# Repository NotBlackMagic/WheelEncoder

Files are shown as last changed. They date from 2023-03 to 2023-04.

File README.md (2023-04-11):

# WheelEncoder
This repository contains the acquisition board hardware and firmware for a Wheel Encoder system developed for the NXP Mobile Robotics Buggy3 Kit, the [MR-Buggy3](https://www.nxp.com/design/designs/mobile-robotics-buggy3-kit-including-rddrone-fmuk66-and-peripherals:MR-BUGGY3). It was initially designed and developed during the NXP [HoverGames3](https://www.hackster.io/contests/nxp-hovergames-challenge-3), as part of my project for this competition: the [AutoSQA](https://www.hackster.io/NotBlackMagic/autonomous-soil-quality-assessment-autosqa-2eb2de). The Wheel Encoder system is composed of an acquisition board, with 4 inputs for HAL sensors (S49e) and multiple interfaces (I2C/UART/CAN), the hardware necessary to mount the HAL sensors to the MR-Buggy3 and the driver for the [PX4 Autopilot](https://px4.io/) to integrate it into this autopilot system, in this case running on the NXP [FMUK66](https://www.nxp.com/design/designs/px4-robotic-drone-vehicle-flight-management-unit-vmu-fmu-rddrone-fmuk66:RDDRONE-FMUK66).

<p align="center">
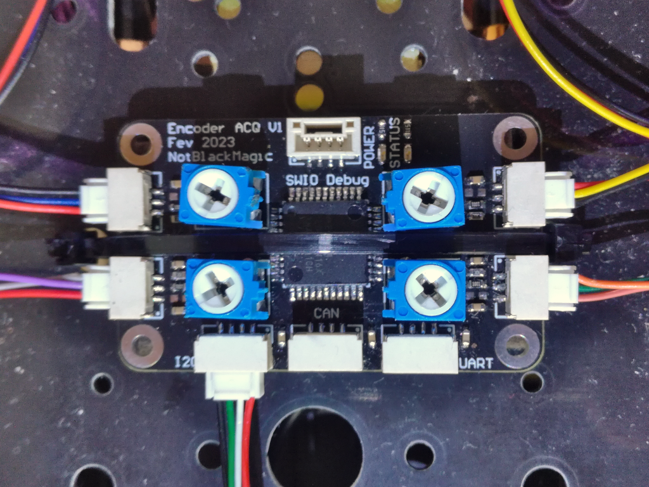
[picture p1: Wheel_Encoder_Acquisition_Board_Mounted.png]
Wheel Encoder Acquisition Board Mounted
	
</p>

More in-depth information and documentation on this Wheel Encoder system can be found on my website: https://notblackmagic.com/projects/wheel-encoder/

Also, a demo video showing how the system works and how it is integrated into the MR-Buggy3 and the PX4 autopilot, can be found on YouTube: https://youtu.be/qfiv8_sycEg

## Folder Structure
This folder contains the firmware code for the Wheel Encoder Acquisition board, developed with the NXP [MCUXpresso IDE](https://www.nxp.com/design/software/development-software/mcuxpresso-integrated-development-environment-ide:MCUXpresso-IDE). The relevant folders/files for this are **"/board, /device, /source, WheelEncoder.mex"**. The remaining folders contain necessary additional files:

**Arduino:** Contains the Arduino code for both the Arduino version of the wheel encoder and a test I2C encoder reader.

**Hardware:** Contains the files for the Wheel Encoder Acquisition board hardware (Gerber + Schematic) and the 3D files (.STL) for the HAL encoder holders for the MR-Buggy3 (WLToys 124019).

## PX4 Firmware
A custom fork of the PX4 firmware, forked from the V1.14 Beta version, contains the driver files for this Wheel Encoder, integrating it into the PX4 autopilot through standard **WheelEncoders.msg** uORB messages. The fork is available on my GitHub:

PX4 fork: https://github.com/NotBlackMagic/PX4-Autopilot/tree/Encoder

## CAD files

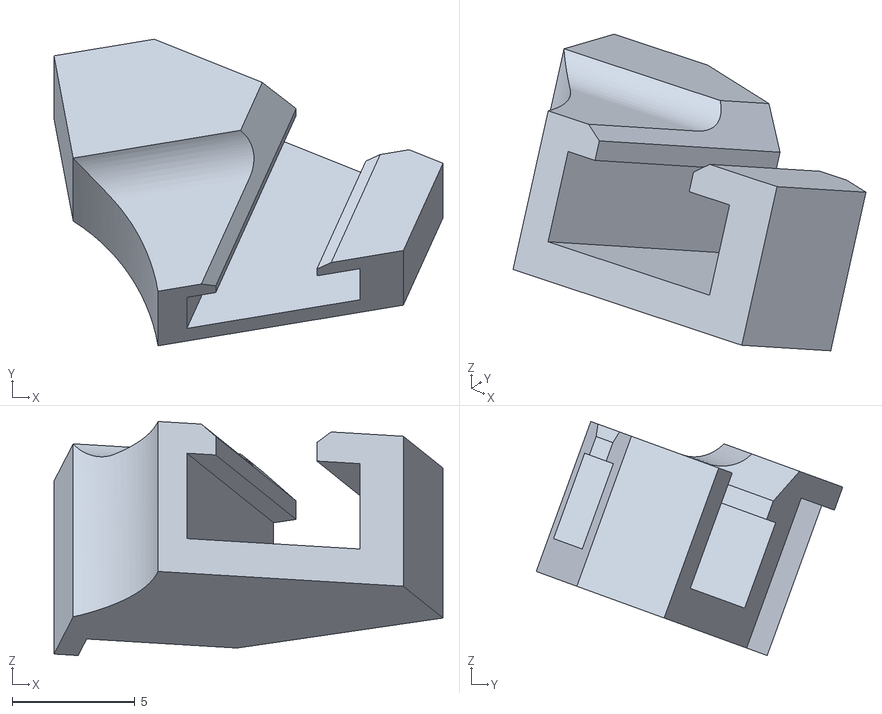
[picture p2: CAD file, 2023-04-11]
Hardware/HAL Holder V1.5 Front Left.stl
15.8 x 12.5 x 9.53

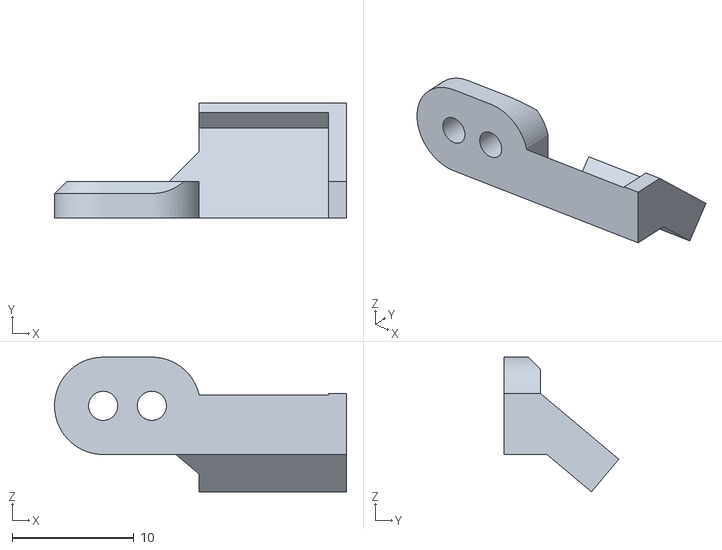
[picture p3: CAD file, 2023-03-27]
Hardware/HAL Holder V2 Back Left.stl
24.0 x 9.42 x 11.1

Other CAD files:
Hardware/HAL Holder V1.5 Front Right.stl.stl
Hardware/HAL Holder V2 Back Right.stl

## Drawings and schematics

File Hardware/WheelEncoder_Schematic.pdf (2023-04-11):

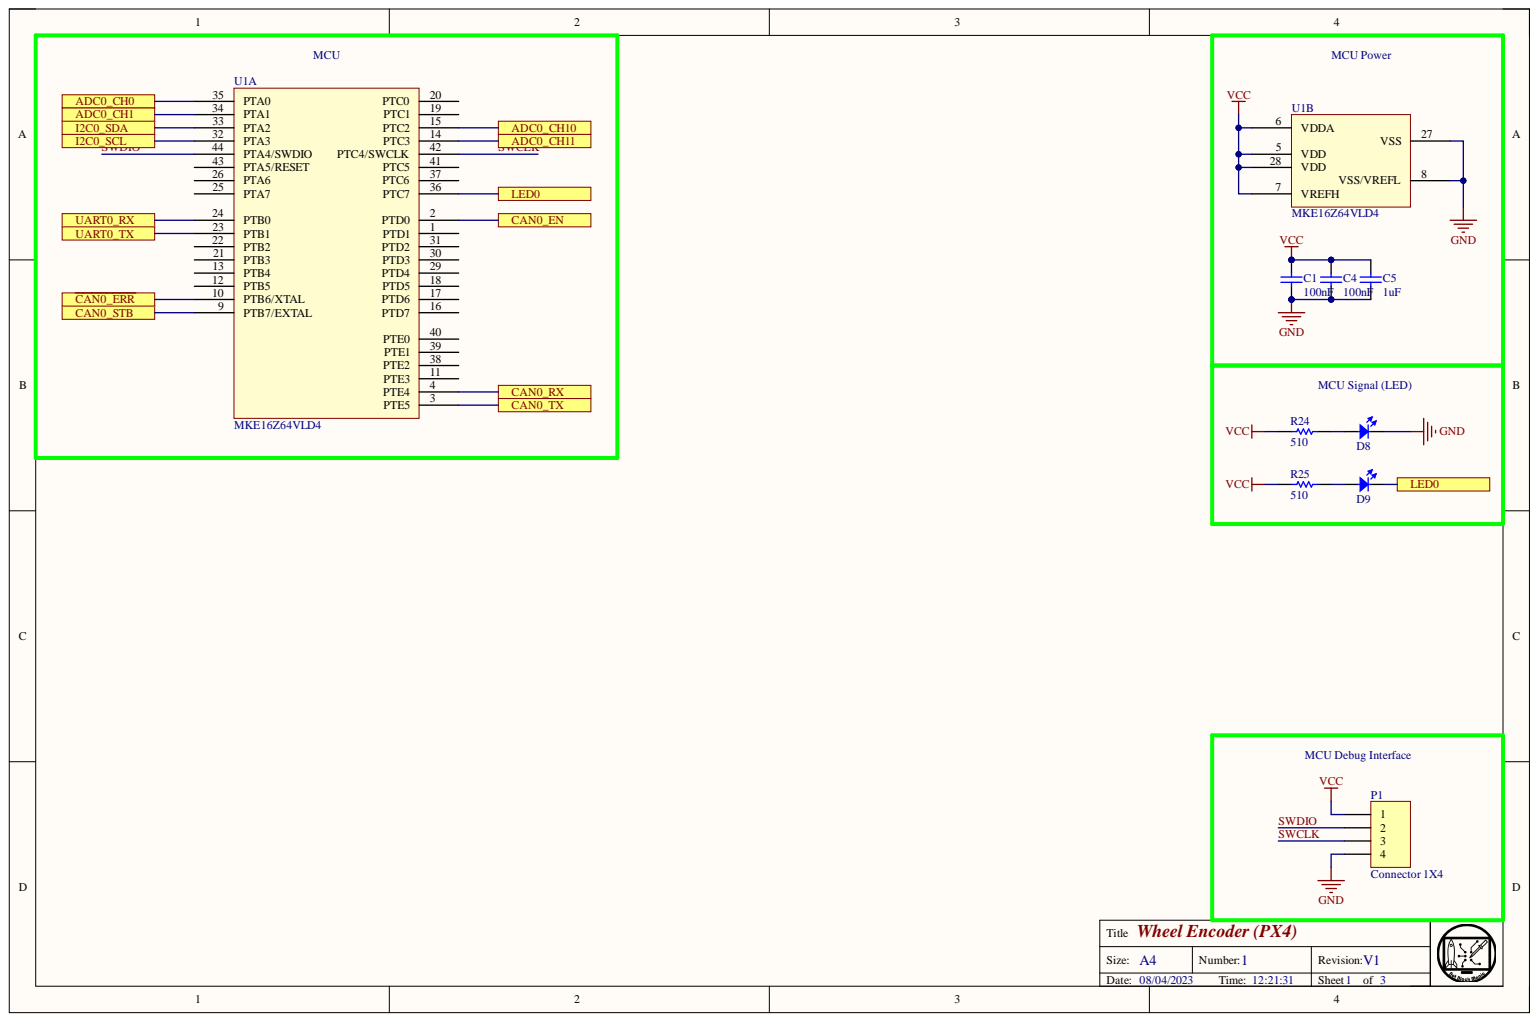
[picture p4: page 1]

VDD 5
VDD 28

Size: A4 | Number: 1 | Revision: V1
Date: 08/04/2023 Time: 12:21:31 | | Sheet 1 of 3

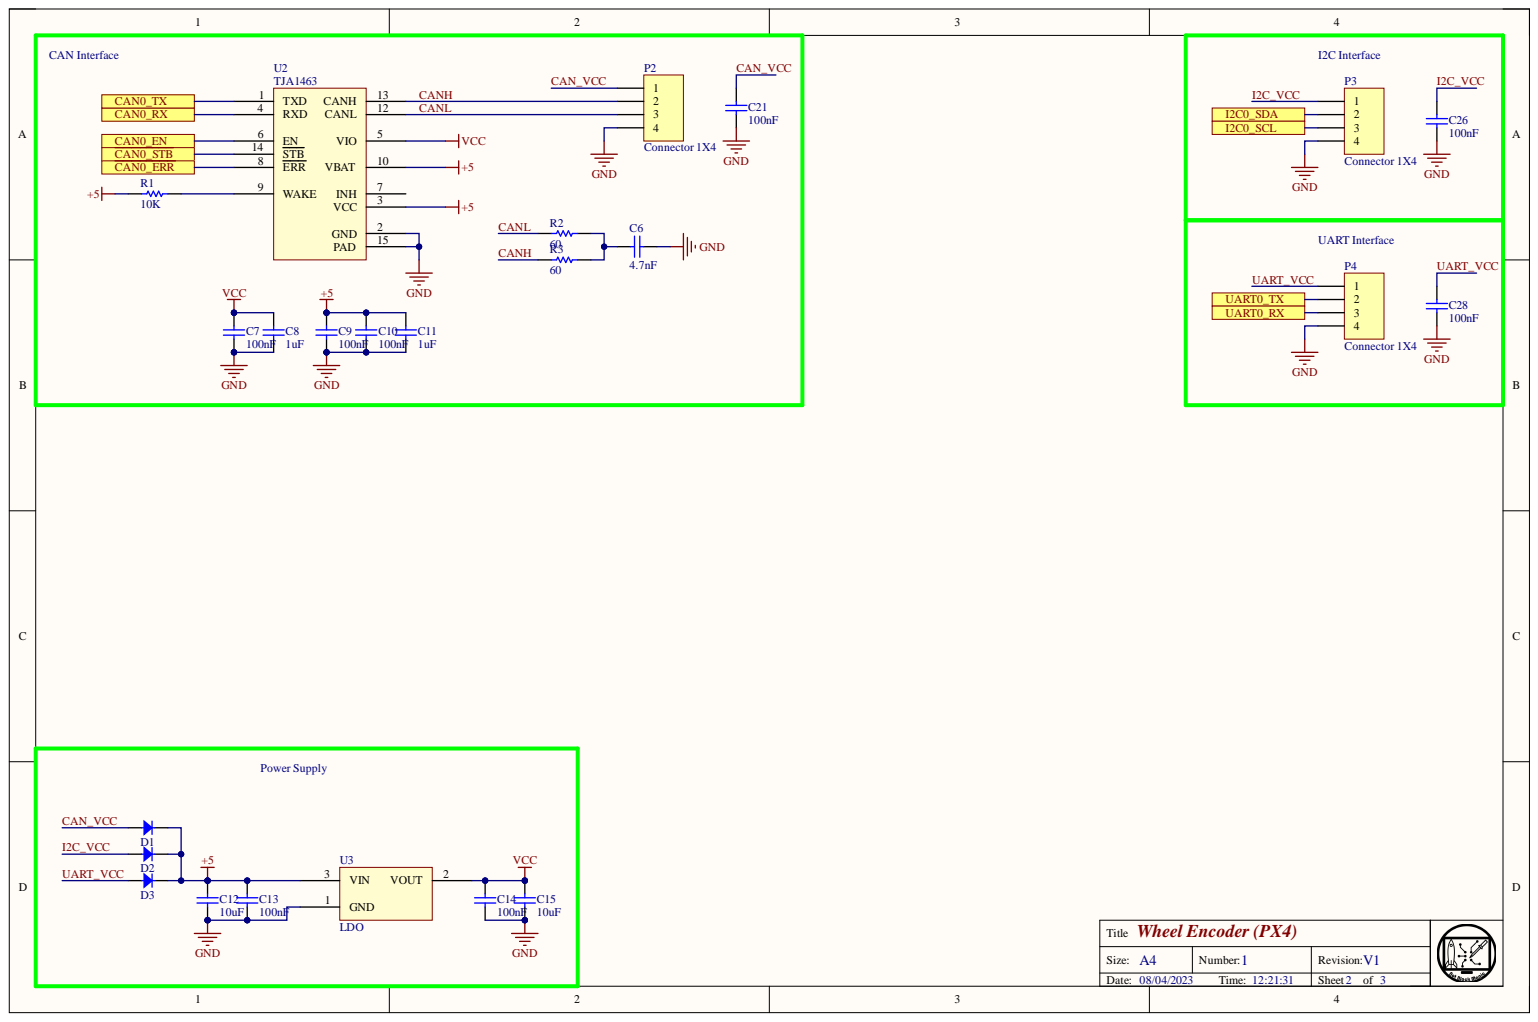
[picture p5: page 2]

Size: A4 | Number: 1 | Revision: V1
Date: 08/04/2023 Time: 12:21:31 | | Sheet 2 of 3

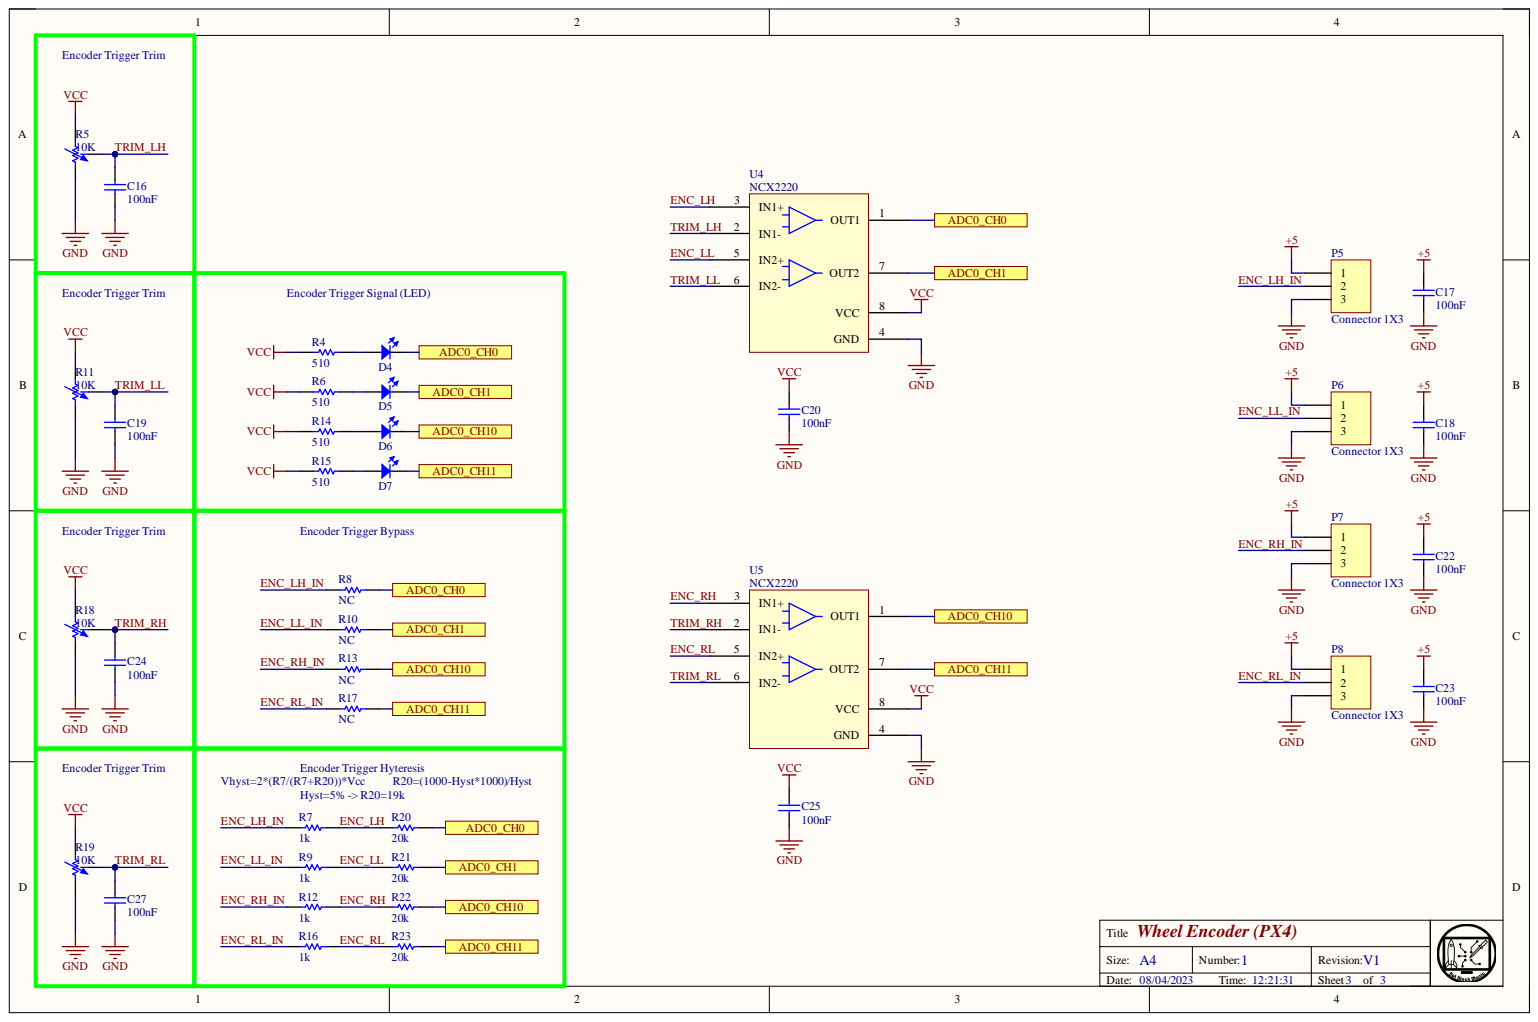
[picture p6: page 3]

VCC G N D

E nco der Tri g ger Tri m VCC 1 0 K TRIM_RL G N D D | der Tri g ger H y teres i s V h y s t=2 *(R7 /(R7+R2 0))* V c c R2 0=(1 0 0 0-H y s t * 1 0 0 0 ) /H y s t H y s t=5 % -> R2 0=1 9 k R7 R2 0 1 k 2 0 k R9 R2 1 1 k 2 0 k R1 2 R2 2 1 k 2 0 k R1 6 R2 3 1 k 2 0 k

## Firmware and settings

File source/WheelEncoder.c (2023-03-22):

#include "stdio.h"
#include "stdint.h"

#include "pin_mux.h"
#include "clock_config.h"
#include "MKE16Z4.h"

#include "fsl_gpio.h"
#include "fsl_lpi2c.h"
#include "fsl_lpuart.h"
#include "fsl_port.h"

//Output Pin Defines
#define GPIO_OUTPUT_LED_PORT			GPIOC
#define GPIO_OUTPUT_LED_PIN				7U
#define GPIO_OUTPUT_CAN_STB_PORT		GPIOB
#define GPIO_OUTPUT_CAN_STB_PIN			7U
#define GPIO_OUTPUT_CAN_EN_PORT			GPIOD
#define GPIO_OUTPUT_CAN_EN_PIN			0U

//Input Pin Defines
#define GPIO_INPUT_HAL_LH_PORT			GPIOA
#define GPIO_INPUT_HAL_LH_PIN			0U
#define GPIO_INPUT_HAL_LL_PORT			GPIOA
#define GPIO_INPUT_HAL_LL_PIN			1U
#define GPIO_INPUT_HAL_RH_PORT			GPIOC
#define GPIO_INPUT_HAL_RH_PIN			2U
#define GPIO_INPUT_HAL_RL_PORT			GPIOC
#define GPIO_INPUT_HAL_RL_PIN			3U
#define GPIO_INPUT_CAN_ERR_PORT			GPIOB
#define GPIO_INPUT_CAN_ERR_PIN			6U

//Interface properties
#define DEVICE_UART_BAUDRATE			115200
#define DEVICE_I2C_ADDR   				0x02
#define DEVICE_CAN_ADDR					0x00
#define DEVICE_ID         				'N'

void Delay(uint32_t ms);

typedef enum Register {
	EncoderID = 0x00,
	EncoderData = 0x01,
	EncoderPPR = 0x02
} Register;

typedef enum EncoderMode {
	Independent_2W_Low,
	Independent_2W_High,
	Independent_4W,
	Quadrature_2W
} EncoderMode;

typedef struct WheelEncoder {
	int16_t ticksPerEvolution;
	int32_t tickCount;
	int16_t rpm;
} WheelEncoder;

EncoderMode encoderMode;
WheelEncoder encoderLeftHigh;
WheelEncoder encoderLeftLow;
WheelEncoder encoderRightHigh;
WheelEncoder encoderRightLow;

//Pin Interrupt Handler for GPIO Ports A and E
void PORTAE_IRQHandler(void) {
	if((GPIO_PortGetInterruptFlags(GPIO_INPUT_HAL_LH_PORT) & (1U << GPIO_INPUT_HAL_LH_PIN)) == (1U << GPIO_INPUT_HAL_LH_PIN)) {
		//GPIOA Pin 0 (PTA0) interrupt
		if(encoderMode == Quadrature_2W) {
			//Quadrature Mode, status of LL gives rotation direction
			if(GPIO_PinRead(GPIO_INPUT_HAL_LL_PORT, GPIO_INPUT_HAL_LL_PIN) == 0x01) {
				encoderLeftHigh.tickCount += 1;
			}
			else {
				encoderLeftHigh.tickCount -= 1;
			}
		}
		else {
			encoderLeftHigh.tickCount += 1;
		}

		//Clear Flag
		GPIO_PortClearInterruptFlags(GPIO_INPUT_HAL_LH_PORT, (1U << GPIO_INPUT_HAL_LH_PIN));
	}
	if((GPIO_PortGetInterruptFlags(GPIO_INPUT_HAL_LL_PORT) & (1U << GPIO_INPUT_HAL_LL_PIN)) == (1U << GPIO_INPUT_HAL_LL_PIN)) {
		//GPIOA Pin 1 (PTA1) interrupt
		if(encoderMode != Quadrature_2W) {
			encoderLeftLow.tickCount += 1;
		}

		//Clear Flag
		GPIO_PortClearInterruptFlags(GPIO_INPUT_HAL_LL_PORT, (1U << GPIO_INPUT_HAL_LL_PIN));
	}
}

//Pin Interrupt Handler for GPIO Ports B, C and D
void PORTBCD_IRQHandler(void) {
	if((GPIO_PortGetInterruptFlags(GPIO_INPUT_HAL_RH_PORT) & (1U << GPIO_INPUT_HAL_RH_PIN)) == (1U << GPIO_INPUT_HAL_RH_PIN)) {
		//GPIOC Pin 2 (PTC2) interrupt
		if(encoderMode == Quadrature_2W) {
			//Quadrature Mode, status of LL gives rotation direction
			if(GPIO_PinRead(GPIO_INPUT_HAL_RH_PORT, GPIO_INPUT_HAL_RH_PIN) == 0x01) {
				encoderRightHigh.tickCount += 1;
			}
			else {
				encoderRightHigh.tickCount -= 1;
			}
		}
		else {
			encoderRightHigh.tickCount += 1;
		}

		//Clear Flag
		GPIO_PortClearInterruptFlags(GPIO_INPUT_HAL_RH_PORT, (1U << GPIO_INPUT_HAL_RH_PIN));
	}
	if((GPIO_PortGetInterruptFlags(GPIO_INPUT_HAL_RL_PORT) & (1U << GPIO_INPUT_HAL_RL_PIN)) == (1U << GPIO_INPUT_HAL_RL_PIN)) {
		//GPIOC Pin 3 (PTC3) interrupt
		if(encoderMode != Quadrature_2W) {
			encoderRightLow.tickCount += 1;
		}

		//Clear Flag
		GPIO_PortClearInterruptFlags(GPIO_INPUT_HAL_RL_PORT, (1U << GPIO_INPUT_HAL_RL_PIN));
	}
}

//UART0 Interrupt Handler
void LPUART0_IRQHandler(void) {

}

uint8_t g_slave_buff[64];
lpi2c_slave_handle_t g_s_handle;
volatile bool g_SlaveCompletionFlag = false;
static void lpi2c_slave_callback(LPI2C_Type *base, lpi2c_slave_transfer_t *xfer, void *param) {
	switch (xfer->event) {
		case kLPI2C_SlaveAddressMatchEvent: {
			//Address match event
			xfer->data = NULL;
			xfer->dataSize = 0;
			break;
		}
		case kLPI2C_SlaveTransmitEvent: {
			//Transmit request
			//Check received data for what to send back
			uint8_t reqRegister = g_slave_buff[0];

			uint8_t txIndex = 0;
			switch(reqRegister) {
				case EncoderID:
					g_slave_buff[txIndex++] = DEVICE_ID;
					break;
				case EncoderData:
					g_slave_buff[txIndex++] = encoderLeftHigh.tickCount >> 24;
					g_slave_buff[txIndex++] = encoderLeftHigh.tickCount >> 16;
					g_slave_buff[txIndex++] = encoderLeftHigh.tickCount >> 8;
					g_slave_buff[txIndex++] = encoderLeftHigh.tickCount;
					g_slave_buff[txIndex++] = encoderLeftHigh.rpm >> 8;
					g_slave_buff[txIndex++] = encoderLeftHigh.rpm;
					g_slave_buff[txIndex++] = encoderRightHigh.tickCount >> 24;
					g_slave_buff[txIndex++] = encoderRightHigh.tickCount >> 16;
					g_slave_buff[txIndex++] = encoderRightHigh.tickCount >> 8;
					g_slave_buff[txIndex++] = encoderRightHigh.tickCount;
					g_slave_buff[txIndex++] = encoderRightHigh.rpm >> 8;
					g_slave_buff[txIndex++] = encoderRightHigh.rpm;
					break;
				case EncoderPPR:
					g_slave_buff[txIndex++] = encoderLeftHigh.ticksPerEvolution >> 8;
					g_slave_buff[txIndex++] = encoderLeftHigh.ticksPerEvolution;
					break;
			}

			//Update information for transmit process
			xfer->data = &g_slave_buff[0];
			xfer->dataSize = txIndex;
			break;
		}
		case kLPI2C_SlaveReceiveEvent: {
			//Receive request
			//Update information for received process
			xfer->data = g_slave_buff;
			xfer->dataSize = 64;
			break;
		}
		case kLPI2C_SlaveCompletionEvent: {
			//Transfer done
			g_SlaveCompletionFlag = true;
			xfer->data = NULL;
			xfer->dataSize = 0;
			break;
		}
		default: {
			g_SlaveCompletionFlag = false;
			break;
		}
	}
}

uint8_t rxBuffer[256];
uint8_t rxBufferLength;
uint8_t txBuffer[256];
uint8_t txBufferLength;
int main(void) {
	//Init
	BOARD_InitBootPins();
	BOARD_InitBootClocks();

	SysTick_Config(CLOCK_GetFreq(kCLOCK_ScgFircClk) / 1000);	//SysTick configured with 1ms timing

	//Init GPIO Output Pins
	gpio_pin_config_t gpioOutputConfig = {
		kGPIO_DigitalOutput,
		0,
	};
	GPIO_PinInit(GPIO_OUTPUT_LED_PORT, GPIO_OUTPUT_LED_PIN, &gpioOutputConfig);				//LED Output
	GPIO_PinInit(GPIO_OUTPUT_CAN_STB_PORT, GPIO_OUTPUT_CAN_STB_PIN, &gpioOutputConfig);		//CAN (TJA1463) Standby
	GPIO_PinInit(GPIO_OUTPUT_CAN_EN_PORT, GPIO_OUTPUT_CAN_EN_PIN, &gpioOutputConfig);		//CAN (TJA1463) Enable

	//Init GPIO Input Pins
	gpio_pin_config_t gpioInputConfig = {
		kGPIO_DigitalInput,
		0,
	};
	GPIO_PinInit(GPIO_INPUT_HAL_LH_PORT, GPIO_INPUT_HAL_LH_PIN, &gpioInputConfig);			//HAL Sensor Left High
	GPIO_PinInit(GPIO_INPUT_HAL_LL_PORT, GPIO_INPUT_HAL_LL_PIN, &gpioInputConfig);			//HAL Sensor Left Low
	GPIO_PinInit(GPIO_INPUT_HAL_RH_PORT, GPIO_INPUT_HAL_RH_PIN, &gpioInputConfig);			//HAL Sensor Right High
	GPIO_PinInit(GPIO_INPUT_HAL_RL_PORT, GPIO_INPUT_HAL_RL_PIN, &gpioInputConfig);			//HAL Sensor Right Low
	GPIO_PinInit(GPIO_INPUT_CAN_ERR_PORT, GPIO_INPUT_CAN_ERR_PIN, &gpioInputConfig);			//CAN (TJA1463) Error

	//Init GPIO Interrupts
	PORT_SetPinInterruptConfig(PORTA, GPIO_INPUT_HAL_LH_PIN, kPORT_InterruptFallingEdge);
	PORT_SetPinInterruptConfig(PORTA, GPIO_INPUT_HAL_LL_PIN, kPORT_InterruptFallingEdge);
	PORT_SetPinInterruptConfig(PORTC, GPIO_INPUT_HAL_RH_PIN, kPORT_InterruptFallingEdge);
	PORT_SetPinInterruptConfig(PORTC, GPIO_INPUT_HAL_RL_PIN, kPORT_InterruptFallingEdge);
	EnableIRQ(PORTAE_IRQn);
	EnableIRQ(PORTBCD_IRQn);

	//Set GPIO Output Pins
	GPIO_PinWrite(GPIO_OUTPUT_LED_PORT, GPIO_OUTPUT_LED_PIN, 0);				//LED Output
	GPIO_PinWrite(GPIO_OUTPUT_CAN_STB_PORT, GPIO_OUTPUT_CAN_STB_PIN, 0);		//CAN (TJA1463) Standby
	GPIO_PinWrite(GPIO_OUTPUT_CAN_EN_PORT, GPIO_OUTPUT_CAN_EN_PIN, 0);			//CAN (TJA1463) Enable

	//Init UART
	/*
	 * config.baudRate_Bps = 115200U;
	 * config.parityMode = kLPUART_ParityDisabled;
	 * config.stopBitCount = kLPUART_OneStopBit;
	 * config.txFifoWatermark = 0;
	 * config.rxFifoWatermark = 0;
	 * config.enableTx = false;
	 * config.enableRx = false;
	 */
	lpuart_config_t config;
	LPUART_GetDefaultConfig(&config);
	config.baudRate_Bps = DEVICE_UART_BAUDRATE;
	config.enableTx     = true;
	config.enableRx     = true;
	LPUART_Init(LPUART0, &config, CLOCK_GetFreq(kCLOCK_ScgFircClk));

	//Init I2C
	/*
	 * slaveConfig.address0 = 0U;
	 * slaveConfig.address1 = 0U;
	 * slaveConfig.addressMatchMode = kLPI2C_MatchAddress0;
	 * slaveConfig.filterDozeEnable = true;
	 * slaveConfig.filterEnable = true;
	 * slaveConfig.enableGeneralCall = false;
	 * slaveConfig.ignoreAck = false;
	 * slaveConfig.enableReceivedAddressRead = false;
	 * slaveConfig.sdaGlitchFilterWidth_ns = 0;
	 * slaveConfig.sclGlitchFilterWidth_ns = 0;
	 * slaveConfig.dataValidDelay_ns = 0;
	 * slaveConfig.clockHoldTime_ns = 0;
	 */
	lpi2c_slave_config_t slaveConfig;
	LPI2C_SlaveGetDefaultConfig(&slaveConfig);
	slaveConfig.address0 = DEVICE_I2C_ADDR;
	LPI2C_SlaveInit(LPI2C0, &slaveConfig, CLOCK_GetIpFreq(kCLOCK_Lpi2c0));
	//Create the LPI2C handle for the non-blocking transfer
	LPI2C_SlaveTransferCreateHandle(LPI2C0, &g_s_handle, lpi2c_slave_callback, NULL);
	//Start accepting I2C transfers on the LPI2C slave peripheral
	int32_t reVal = LPI2C_SlaveTransferNonBlocking(LPI2C0, &g_s_handle, kLPI2C_SlaveCompletionEvent | kLPI2C_SlaveAddressMatchEvent);
	if(reVal != kStatus_Success) {

	}

	//Send over UART
	txBufferLength = sprintf(txBuffer, "Wheel Encoder Boot Complete!");
	LPUART_WriteBlocking(LPUART0, txBuffer, txBufferLength);
//	LPUART_WriteByte(LPUART0, demoRingBuffer[txIndex]);

	//Enable RX Interrupt
//	LPUART_EnableInterrupts(LPUART0, kLPUART_RxDataRegFullInterruptEnable);
//	EnableIRQ(LPUART0_IRQn);

	//Init encoder
	encoderMode = Independent_4W;
	encoderLeftHigh.ticksPerEvolution = 2;
	encoderLeftHigh.tickCount = 0;
	encoderLeftHigh.rpm = 0;
	encoderLeftLow.ticksPerEvolution = 2;
	encoderLeftLow.tickCount = 0;
	encoderLeftLow.rpm = 0;
	encoderRightHigh.ticksPerEvolution = 2;
	encoderRightHigh.tickCount = 0;
	encoderRightHigh.rpm = 0;
	encoderRightLow.ticksPerEvolution = 2;
	encoderRightLow.tickCount = 0;
	encoderRightLow.rpm = 0;

	uint8_t ledState = 0;
	while(1) {
		txBufferLength = sprintf(txBuffer, "LH: %d, LL: %d, RH: %d, RL: %d\n", encoderLeftHigh.tickCount, encoderLeftLow.tickCount, encoderRightHigh.tickCount, encoderRightLow.tickCount);
		LPUART_WriteBlocking(LPUART0, txBuffer, txBufferLength);

		GPIO_PinWrite(GPIO_OUTPUT_LED_PORT, GPIO_OUTPUT_LED_PIN, ledState);
		ledState = !ledState;
		Delay(1000);
	}
}

void HardFault_Handler(void) {

}

volatile uint32_t systick = 0;
void SysTick_Handler(void) {
	systick += 1;
}

void Delay(uint32_t ms) {
	uint32_t timestamp = systick + ms;
	while(systick < timestamp);
}

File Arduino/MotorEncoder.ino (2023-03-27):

#include "Wire.h"

#define DEVICE_I2C_ADDR   0x02

#define DEVICE_ID         'N'

enum Register {
  EncoderID = 0x00,
  EncoderData = 0x01,
  EncoderPPR = 0x02
};

//Interface settings
const uint32_t baudrate = 115200;

const uint8_t LEFT_WHEEL = 0;
const uint8_t RIGHT_WHEEL = 1;

//Pin mapping
const uint8_t hallSensor[2] = {A0, A1};

//Encoder processing variables
const int16_t hallMeanValue[2] = {470, 523};
const int16_t hallRisingThreshold[2] = {150, 150};
const int16_t hallFallingThreshold[2] = {100, 100};  
int16_t hallAnalogValue[2] = {0, 0};
uint8_t hallTriggered[2] = {0, 0};

const uint16_t encoderPulsesPerRevolution = 1;
int32_t lastEncoderCount[2] = {0, 0};
int32_t encoderCount[2] = {0, 0};
int16_t rpm[2] = {0, 0};

int16_t rpmCounter = 0;
uint32_t timestamp = 0;

//I2C interface handling variables
Register i2cRegisterRequest = 0;

void setup() {
  //Config GPIOs
  //pinMode(hallSensorI, INPUT_PULLUP);
  //pinMode(hallSensorQ, INPUT_PULLUP);

  //Config Interrupts
  //attachInterrupt(digitalPinToInterrupt(hallSensorI), HallSensorI_IRQ, RISING);
  //attachInterrupt(digitalPinToInterrupt(hallSensorQ), HallSensorQ_IRQ, RISING);

  //Config digital interfaces
  Serial.begin(baudrate);
  Wire.begin(DEVICE_I2C_ADDR);
  Wire.onReceive(I2CRX_IRQ);
  Wire.onRequest(I2CReq_IRQ);
}

void loop() {
  //Read analog values
  hallAnalogValue[LEFT_WHEEL] = analogRead(hallSensor[LEFT_WHEEL]) - hallMeanValue[LEFT_WHEEL];
  hallAnalogValue[RIGHT_WHEEL] = analogRead(hallSensor[RIGHT_WHEEL]) - hallMeanValue[RIGHT_WHEEL];

  //Convert to absolute value
  if(hallAnalogValue[LEFT_WHEEL] < 0) {
    hallAnalogValue[LEFT_WHEEL] = -hallAnalogValue[LEFT_WHEEL];
  }
  if(hallAnalogValue[RIGHT_WHEEL] < 0) {
    hallAnalogValue[RIGHT_WHEEL] = -hallAnalogValue[RIGHT_WHEEL];
  }

  //Check for HAL sensor triggers
  if(hallTriggered[LEFT_WHEEL] == 0 && hallAnalogValue[LEFT_WHEEL] >= hallRisingThreshold[LEFT_WHEEL]) {
    encoderCount[LEFT_WHEEL] += 1;

    hallTriggered[LEFT_WHEEL] = 1;
  }
  else if(hallTriggered[LEFT_WHEEL] == 1 && hallAnalogValue[LEFT_WHEEL] <= hallFallingThreshold[LEFT_WHEEL]) {
    hallTriggered[LEFT_WHEEL] = 0;
  }

  if(hallTriggered[RIGHT_WHEEL] == 0 && hallAnalogValue[RIGHT_WHEEL] >= hallRisingThreshold[RIGHT_WHEEL]) {
    encoderCount[RIGHT_WHEEL] += 1;

    hallTriggered[RIGHT_WHEEL] = 1;
  }
  else if(hallTriggered[RIGHT_WHEEL] == 1 && hallAnalogValue[RIGHT_WHEEL] <= hallFallingThreshold[RIGHT_WHEEL]) {
    hallTriggered[RIGHT_WHEEL] = 0;
  }

  // Serial.print("L:");
  // Serial.print(hallAnalogValue[LEFT_WHEEL]);
  // Serial.print(",R:");
  // Serial.println(hallAnalogValue[RIGHT_WHEEL]);

  if((timestamp + 100) < millis()) {
    if(rpmCounter == 0) {
      //Calculate RPM value, updated every 1s aka 1 Hz
      rpm[LEFT_WHEEL] = ((encoderCount[LEFT_WHEEL] - lastEncoderCount[LEFT_WHEEL]) * 60) / encoderPulsesPerRevolution;
      lastEncoderCount[LEFT_WHEEL] = encoderCount[LEFT_WHEEL];

      rpm[RIGHT_WHEEL] = ((encoderCount[RIGHT_WHEEL] - lastEncoderCount[RIGHT_WHEEL]) * 60) / encoderPulsesPerRevolution;
      lastEncoderCount[RIGHT_WHEEL] = encoderCount[RIGHT_WHEEL];

      rpmCounter = 10;
    }
    rpmCounter -= 1;

    // Serial.print("Encoder: L: ");
    // Serial.print(encoderCount[LEFT_WHEEL]);
    // Serial.print("/");
    // Serial.print(rpm[LEFT_WHEEL]);
    // Serial.print(" R: ");
    // Serial.print(encoderCount[RIGHT_WHEEL]);
    // Serial.print("/");
    // Serial.println(rpm[RIGHT_WHEEL]);

    timestamp = millis();
  }
}

void I2CRX_IRQ(int count) {
  //I2C RX IRQ Handler
  i2cRegisterRequest = Wire.read();
  if(count > 1) {
    //This is a I2C write request, get all bytes with Wire.read()
  }
  //Just in case, clean up I2C rx buffer
  while(Wire.available() == true) {
    Wire.read();
  }
}

void I2CReq_IRQ() {
  uint8_t txDataIndex = 0;
  uint8_t txData[20];
  //I2C data request (read) IRQ Handler
  switch(i2cRegisterRequest) {
    case EncoderID: {
      txData[txDataIndex++] = DEVICE_ID;
      Wire.write(txData, txDataIndex);
      break;
    }
    case EncoderData: {
      txData[txDataIndex++] = encoderCount[LEFT_WHEEL] >> 24;
      txData[txDataIndex++] = encoderCount[LEFT_WHEEL] >> 16;
      txData[txDataIndex++] = encoderCount[LEFT_WHEEL] >> 8;
      txData[txDataIndex++] = encoderCount[LEFT_WHEEL];
      txData[txDataIndex++] = rpm[LEFT_WHEEL] >> 8;
      txData[txDataIndex++] = rpm[LEFT_WHEEL];
      txData[txDataIndex++] = encoderCount[RIGHT_WHEEL] >> 24;
      txData[txDataIndex++] = encoderCount[RIGHT_WHEEL] >> 16;
      txData[txDataIndex++] = encoderCount[RIGHT_WHEEL] >> 8;
      txData[txDataIndex++] = encoderCount[RIGHT_WHEEL];
      txData[txDataIndex++] = rpm[RIGHT_WHEEL] >> 8;
      txData[txDataIndex++] = rpm[RIGHT_WHEEL];
      Wire.write(txData, txDataIndex);
      break;
    }
    case EncoderPPR: {
      txData[txDataIndex++] = encoderPulsesPerRevolution >> 8;
      txData[txDataIndex++] = encoderPulsesPerRevolution;
      Wire.write(txData, txDataIndex);
      break;
    }
  }
}

// void HallSensorI_IRQ() {
//   encoderCount += 1;
// }

// void HallSensorQ_IRQ() {
//   encoderCount += 1;
// }

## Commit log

2023-03-27 -Added Arduino prototype code -Added HAL Holder .stl files
    [HAL Holder V2 Left.stl, HAL Holder V2 Right.stl]
2023-04-11 -Added front holder .stl files -Updated schematic (more annotations) -Added readme text -Added top view image
    [HAL Holder V1.5 Front Left.stl, HAL Holder V1.5 Front Right.stl.stl, HAL Holder V2 Back Left.stl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]
